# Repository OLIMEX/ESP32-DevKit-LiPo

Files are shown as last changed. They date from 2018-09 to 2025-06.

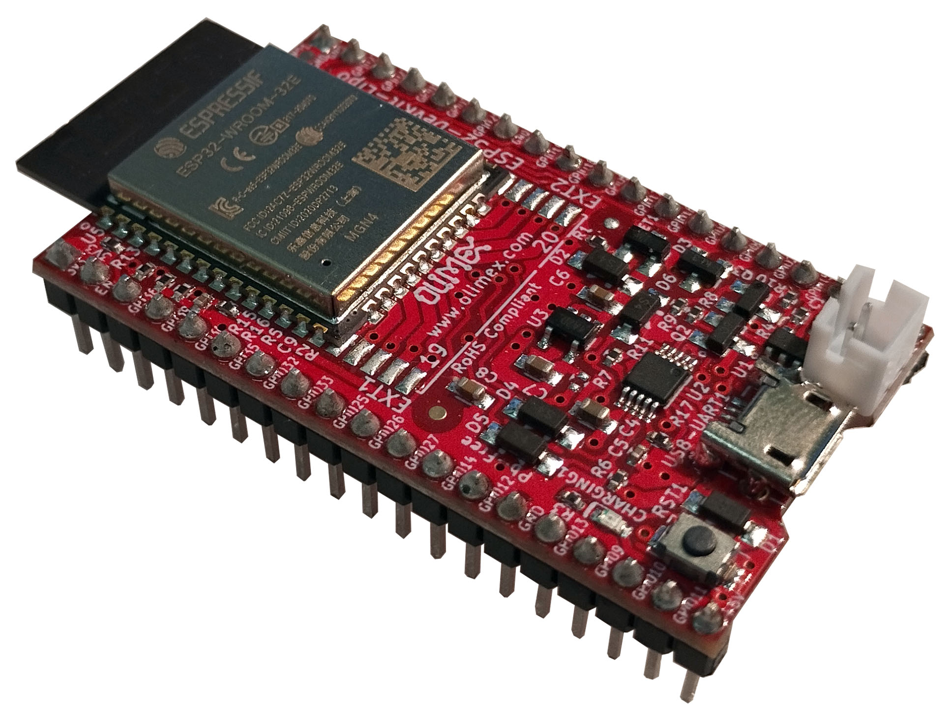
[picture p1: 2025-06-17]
DOCS/side-devkit.jpg

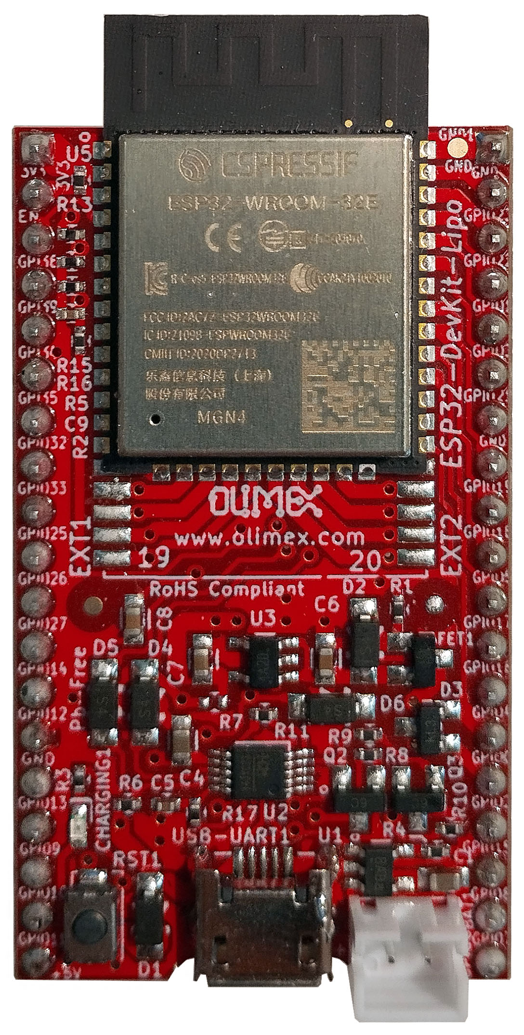
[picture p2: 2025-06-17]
DOCS/top-devkit.jpg

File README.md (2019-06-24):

# ESP32-DevKit-LiPo
Open Source Hardware OSHW ESP32 development board designed with KiCAD to be pin to pin compatible with Espressif ESP32-DevKitC, but with additional LiPo charger and battery

## License
* Hardware is released under Apache 2.0 License
* Software is released under GPL3 License
* Documentation is released under CC BY-SA 3.0

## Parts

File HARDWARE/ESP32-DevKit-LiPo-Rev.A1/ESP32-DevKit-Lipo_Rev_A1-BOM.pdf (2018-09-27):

# ESP32-DevKit-Lipo_Rev_A1-BOM 14.09.2018

Quantity | Designation | Package | Designator
3 | 220R/R0603 | R0603 | R6,R7,R10
3 | 1k/R0603 | R0603 | R8,R9,R13
1 | 1.1k/1%/R0603 | R0603 | R12
3 | 2.2k/R0603 | R0603 | R2,R3,R4
1 | 4.99k/1%/R0603 | R0603 | R11
1 | 10k/R0603 | R0603 | R1
1 | 2.2uH/1.5A/DCR<0.1R/CD32 | CD32 | L1
2 | 27pF/50V/5%/C0G/C0603 | C0603 | C2,C3
1 | 100nF/50V/20%/Y5V/C0603 | C0603 | C5
1 | 22uF/6.3V/20%/X5R/C0603 | C0603 | C4
3 | 47uF/6.3V/20%/X5R/C0805 | C0805 | C1,C6,C7
1 | BAT54C(SOT23-3) | SOT23-3 | U4
2 | 1N5822/SS34/SMA | SMA-KA | D1,D2
1 | LED/YELLOW/0603 | LED_0603 | CHARGING1
1 | LED/RED/0603 | LED_0603 | PWRLED1
2 | BC817-40(SOT23) | SOT23 | Q2,Q3
1 | WPM2015-3/TR | SOT23 | FET1
1 | BL4054B-42TPRN(SOT23-5) | SOT-23-5 | U1
1 | CH340T(SSOP20W) | SSOP-20W | U2
1 | SY8089AAAC(SOT23-5) | SOT-23-5 | U3
1 | ESP-WROOM-32 | MODULE | U5
1 | MISB-SWMM-5B-LF(USB_MICRO) | MISB-SWMM-5B_LF | USB-UART1
1 | Q12MHz/20pF/10ppm/4P/3.2x2.5mm | 3.2x2.5mm | Q1
1 | DW02S | DW02R | BAT1
2 | HN1x19 | HN1x19 | EXT1,EXT2
1 | IT-1185AU2-160G-G-TR | IT1185AU2 | RST1
2 | NA/R0603 | R0603 | R5,R14

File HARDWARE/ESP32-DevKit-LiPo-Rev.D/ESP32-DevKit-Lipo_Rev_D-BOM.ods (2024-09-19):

Qty | Designation | Package | Designator
1 | 220R/R0402 | R_0402_5MIL_DWS | R10
4 | 2.2k/R0402 | R_0402_5MIL_DWS | R9,R3,R4,R8
1 | 4.7k/R0402 | R_0402_5MIL_DWS | R11
4 | 10k/R0402 | R_0402_5MIL_DWS | R1,R6,R13,R17
1 | 220k/R0402 | R_0402_5MIL_DWS | R15
3 | 470k/R0402 | R_0402_5MIL_DWS | R2,R5,R16
2 | 100nF/10V/10%/X7R/C0402 | C_0402_5MIL_DWS | C5,C9
1 | 1uF/10V/10%/X5R/C0603 | C_0603_5MIL_DWS | C8
2 | 4.7uF/6.3V/C0603 | C_0603_5MIL_DWS | C6,C7
2 | 22uF/6.3V/20%/X5R/C0603 | C_0603_5MIL_DWS | C1,C4
5 | 1N5819S4/SOD123 | SOD-123_1C-2A_KA | D5,D4,D1,D2,D6
1 | BAT54C(SOT23-3) | SOT23-3 | D3
1 | LED/YELLOW/0603 | LED_0603_KA | CHARGING1
2 | BC817-40(SOT23) | SOT23 | Q3,Q2
1 | WPM2015-3/TR | SOT23 | FET1
1 | CH340X(MSOP-10) | MSOP-10_Pitch-0.5mm _3.00x3.00x1.00mm | U2
1 | ESP32-WROOM-32D-4MB | ESP32-WROVER_MODULE | U5
1 | HX6211A332MR | SOT-23-5 | U3
1 | BL4054B-42TPRN(SOT23-5) | SOT-23-5 | U1
1 | MISB-SWMM-5B-LF(USB_MICRO) | USB-MICRO_MISB-SWMM-5B_LF | USB-UART1
1 | DW02S | LIPO_BAT_VERTICAL_DW02S | BAT1
2 | HN1x19 | HN1x19 | EXT1,EXT2
1 | IT-1185AU2-160G-G-TR | IT1185AU2_V2 | RST1
3 | Opened | SJ_1_SMALLER | BAT_PWR_E1,BAT_SENS_E1, PWR_SENS_E1
1 | NA/R0402 | R_0402_5MIL_DWS | R7

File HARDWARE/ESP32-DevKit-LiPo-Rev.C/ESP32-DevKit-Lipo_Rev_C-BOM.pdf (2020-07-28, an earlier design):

16:26:48 | ESP32-DevKit-Lipo_Rev_C-BOM 03/19/2020
Quantity | Designation | Package | Designator
1 | 220R/R0402 | R0402 | R10
4 | 2.2k/R0402 | R0402 | R3,R4,R8,R9
4 | 10k/R0402 | R0402 | R1,R6,R13,R17
1 | 49.9k/1%/R0402 | R0402 | R12
2 | 220k/R0402 | R0402 | R11,R15
3 | 470k/R0402 | R0402 | R2,R5,R16
1 | 2.2uH/1.5A/DCR=72mR/20%/ 3.00x3.00x1.50mm/ CD32(NR3015T2R2M) | CD32 | L1
2 | 27pF/50V/5%/C0G/C0402 | C0402 | C2,C3
2 | 100nF/10V/10%/X7R/C0402 | C0402 | C5,C9
1 | 1uF/10V/10%/X5R/C0603 | C0603 | C8
4 | 22uF/6.3V/20%/X5R/C0603 | C0603 | C4,C1,C6,C7
1 | LED/YELLOW/0603 | LED_0603 | CHARGING1
1 | BAT54C(SOT23-3) | SOT23-3 | D3
4 | 1N5819S4/SOD123 | SOD-123 | D1,D2,D4,D5
2 | BC817-40(SOT23) | SOT23 | Q2,Q3
1 | WPM2015-3/TR | SOT23 | FET1
1 | BL4054B-42TPRN(SOT23-5) | SOT-23-5 | U1
1 | CH340T(SSOP20W) | SSOP-20W | U2
1 | SY8089AAAC(SOT23-5) | SOT-23-5 | U3
1 | Q12MHz/20pF/10ppm/4P/3.2x2.5mm | TSX-3.2x2.5mm | Q1
1 | MISB-SWMM-5B-LF(USB_MICRO) | MISB-SWMM-5B_LF | USB-UART1
1 | IT-1185AU2-160G-G-TR | IT1185AU2 | RST1
1 | DW02S | DW02S | BAT1
2 | HN1x19 | HN1x19 | EXT1,EXT2
1 | ESP32-WROOM-32D-4MB | ESP32-MODULE_Universal | U5
3 | Opened | SJ
1 | NA/R0402 | R0402 | R7 BAT_PWR_E1, BAT_SENS_E1, PWR_SENS_E1

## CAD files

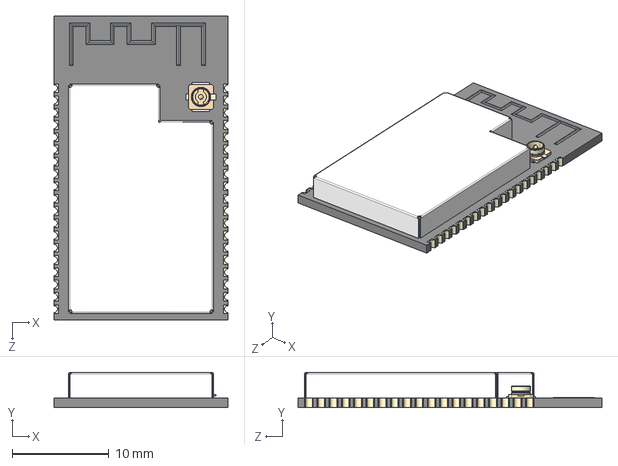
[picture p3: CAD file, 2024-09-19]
HARDWARE/ESP32-DevKit-LiPo-Rev.D/3d/ESP32-WROVER-I-56544.STEP
18.0 x 3.65 x 31.4 mm

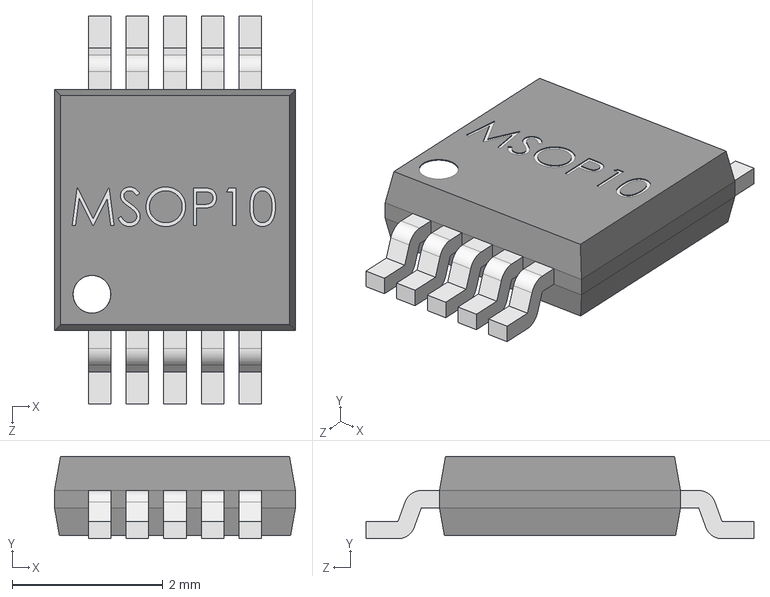
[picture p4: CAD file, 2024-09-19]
HARDWARE/ESP32-DevKit-LiPo-Rev.D/3d/MSOP10-1.step
3.20 x 1.10 x 5.15 mm

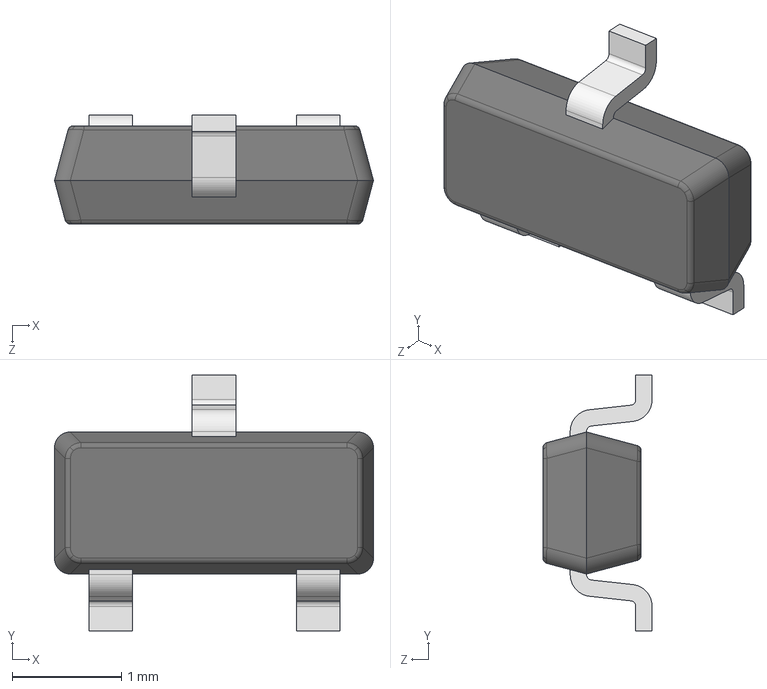
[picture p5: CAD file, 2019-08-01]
HARDWARE/ESP32-DevKit-LiPo-Rev.D/3d/BAT54.step
2.92 x 2.34 x 1.00 mm

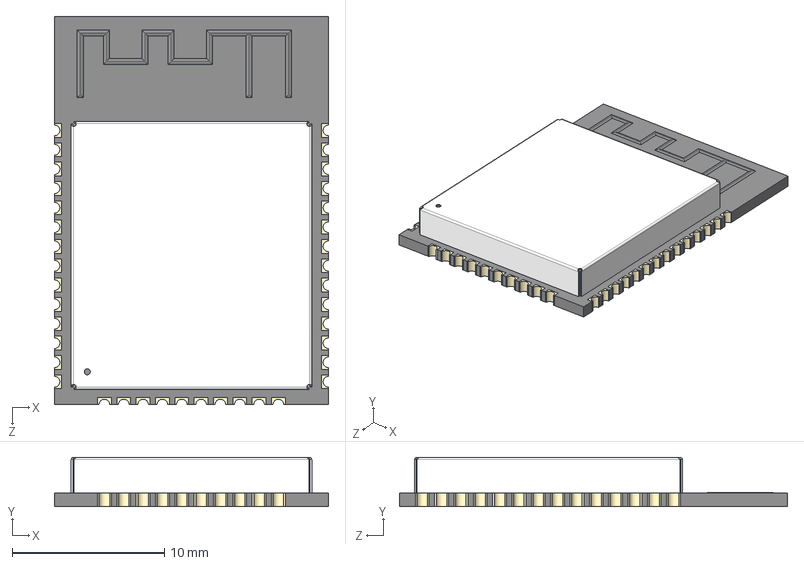
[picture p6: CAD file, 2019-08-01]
HARDWARE/ESP32-DevKit-LiPo-Rev.D/3d/ESP32-WROOM-32D-56544.STEP
18.0 x 3.25 x 25.5 mm

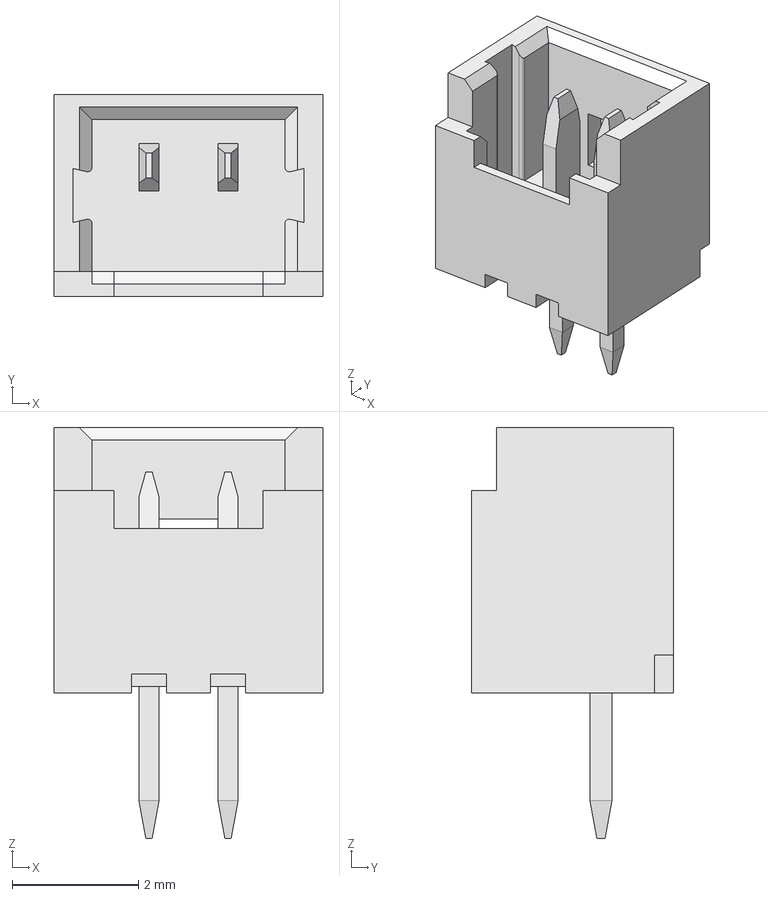
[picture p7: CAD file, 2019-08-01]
HARDWARE/ESP32-DevKit-LiPo-Rev.D/3d/Molex_PicoBlade_530470210.step
4.25 x 3.20 x 6.50 mm

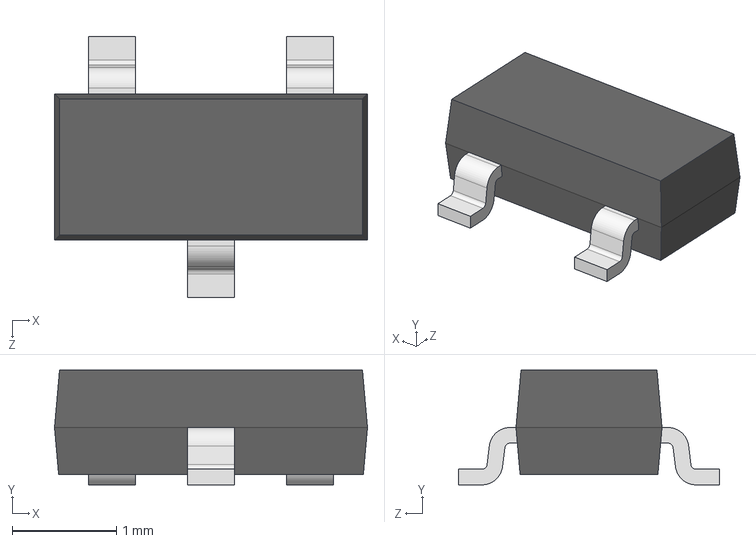
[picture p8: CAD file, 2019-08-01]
HARDWARE/ESP32-DevKit-LiPo-Rev.D/3d/SOT-23.step
3.00 x 1.10 x 2.50 mm

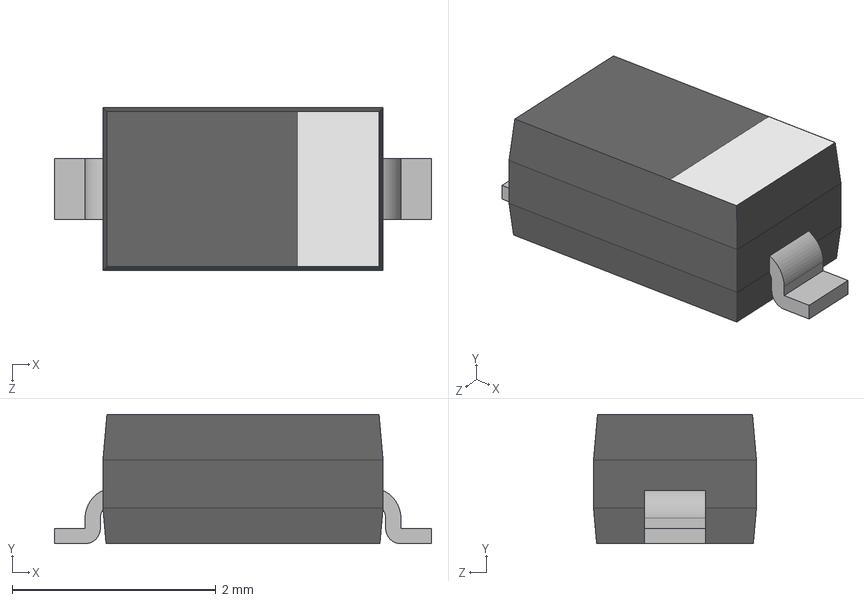
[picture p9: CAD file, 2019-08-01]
HARDWARE/ESP32-DevKit-LiPo-Rev.D/3d/SOD123.step
3.70 x 1.27 x 1.60 mm

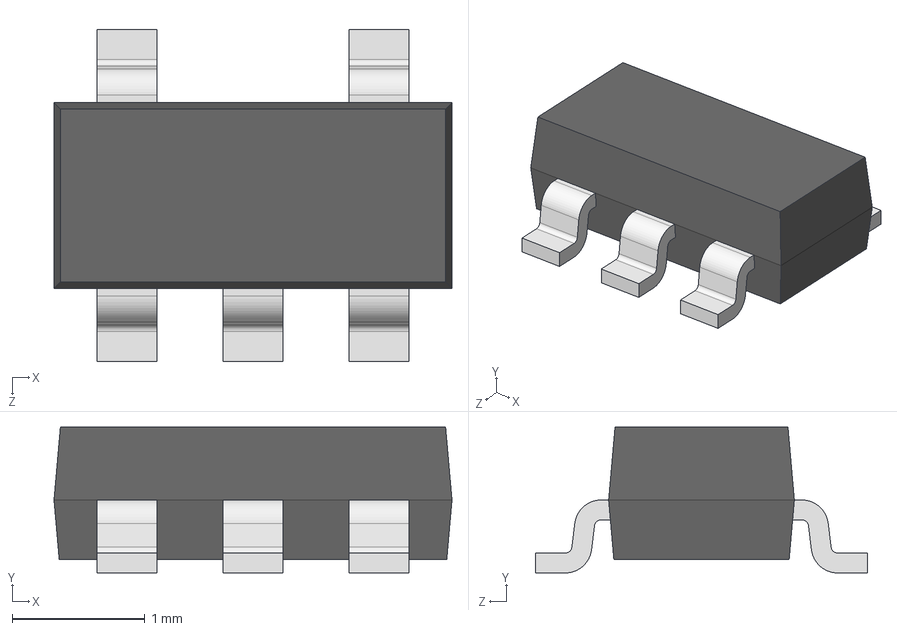
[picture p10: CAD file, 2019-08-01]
HARDWARE/ESP32-DevKit-LiPo-Rev.D/3d/SOT-23-5.step
3.00 x 1.10 x 2.50 mm

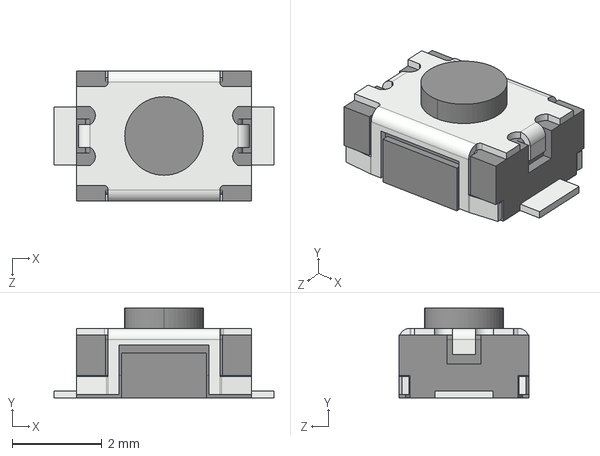
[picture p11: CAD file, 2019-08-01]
HARDWARE/ESP32-DevKit-LiPo-Rev.D/3d/it1185.step
4.90 x 2.00 x 2.90 mm

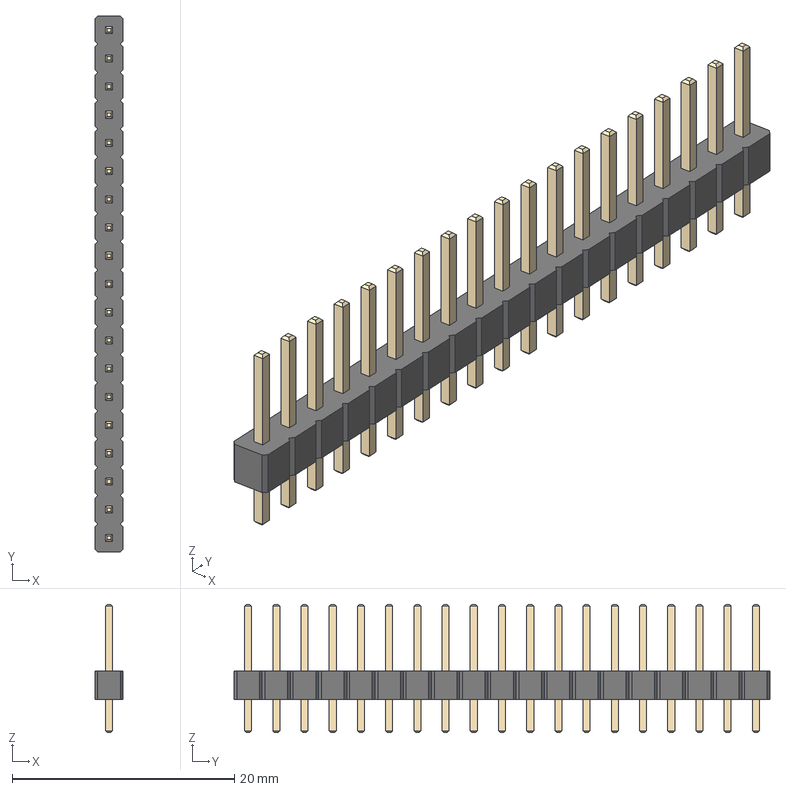
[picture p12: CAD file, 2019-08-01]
HARDWARE/ESP32-DevKit-LiPo-Rev.D/3d/HN1x19-PinHeader_1x19_P2.54mm_Vertical.step
2.54 x 48.3 x 11.5 mm

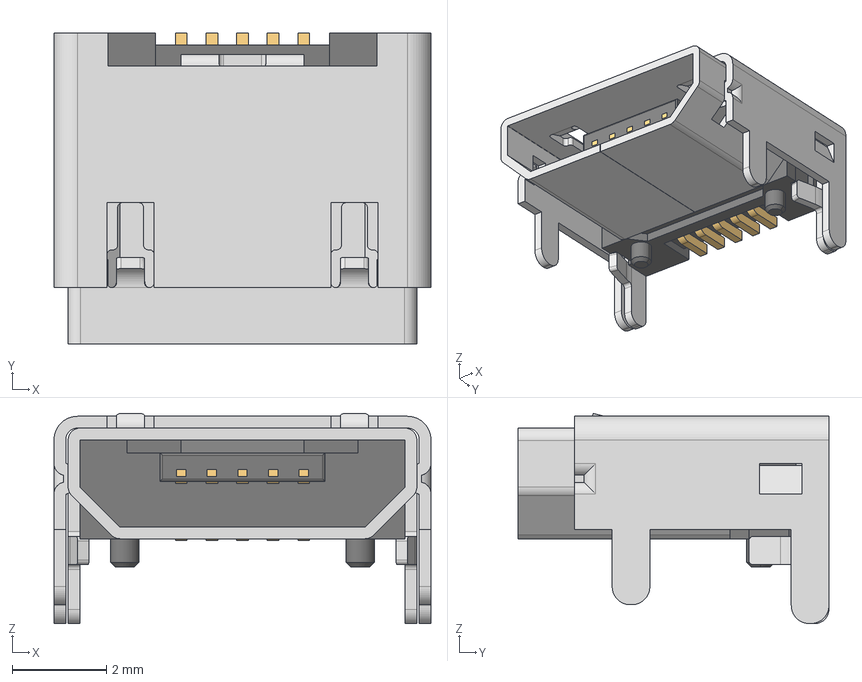
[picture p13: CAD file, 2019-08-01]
HARDWARE/ESP32-DevKit-LiPo-Rev.D/3d/usb_micro_4p.stp
8.00 x 6.60 x 4.46 mm

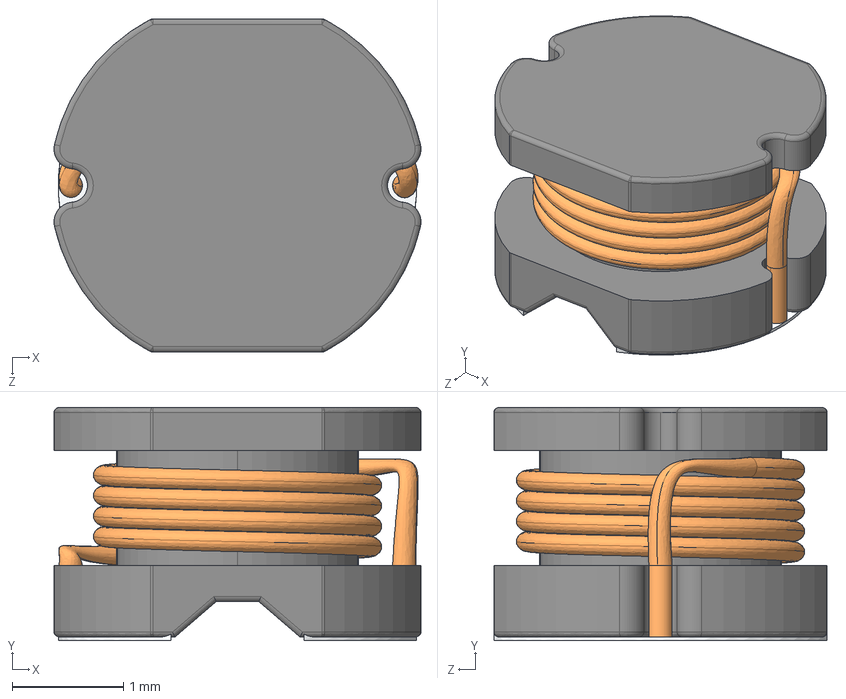
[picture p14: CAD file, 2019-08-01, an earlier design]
HARDWARE/ESP32-DevKit-LiPo-Rev.B/3d/CD32_inductor.step
3.30 x 2.10 x 3.00 mm

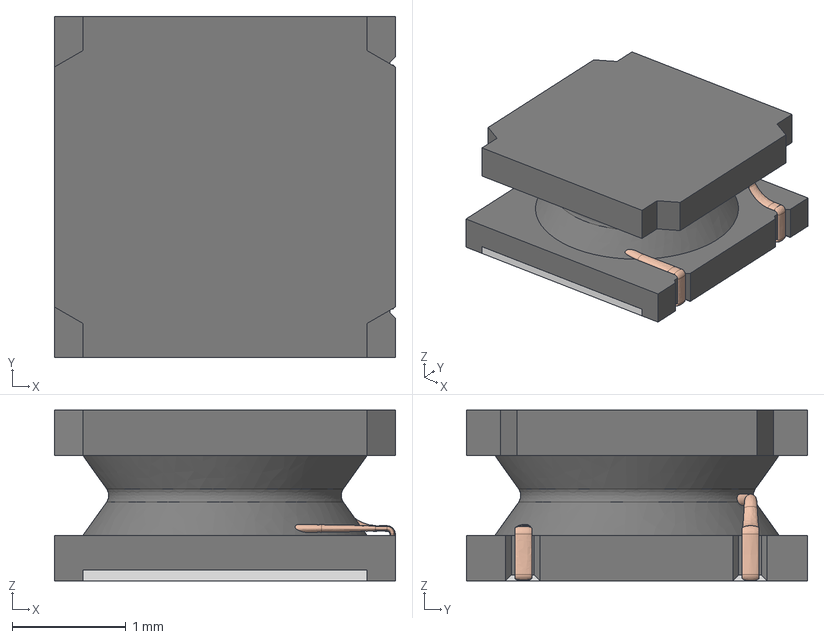
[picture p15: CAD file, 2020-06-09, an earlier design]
HARDWARE/ESP32-DevKit-LiPo-Rev.C/3d/L-CD32_shielded.step
3.00 x 3.00 x 1.50 mm

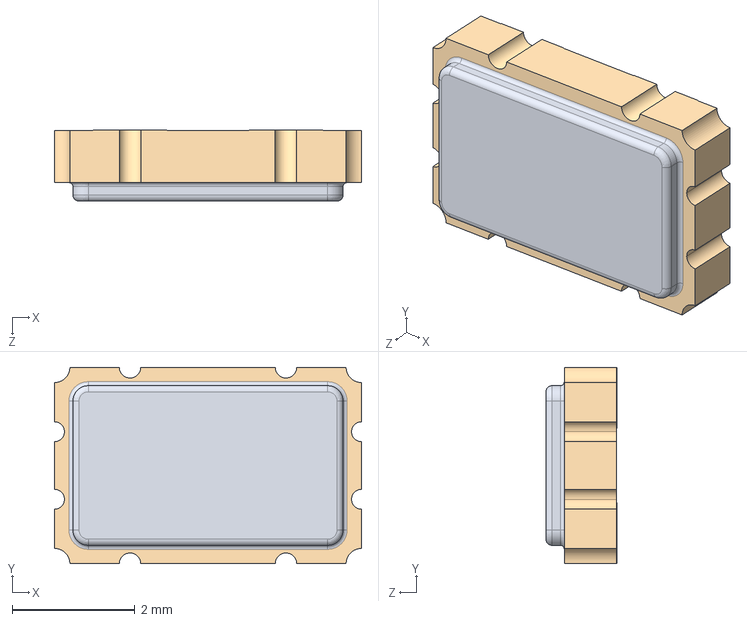
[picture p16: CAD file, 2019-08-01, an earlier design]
HARDWARE/ESP32-DevKit-LiPo-Rev.C/3d/QSG5032.step
5.00 x 3.20 x 1.16 mm

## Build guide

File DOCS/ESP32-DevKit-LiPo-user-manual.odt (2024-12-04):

=


ESP32-DevKit-LiPo

User’s Manual

Document revision 1.0, Devember 2024 | www.olimex.com

# 1. What is ESP32-DevKit-LiPo

ESP32-DevKit-LiPo is an Open Source Hardware development board that incorporates an ESP32 module. The ESP32-DevKit-LiPo board is designed and manufactured by Olimex, while the ESP32 module is designed and manufactured by Espressif systems. The design is inspired by ESP32-CoreBoard (ESP32-DevKitC) and has the same pinout, but adds Li-Po battery connector and charger. The board can operate on a Li-Po power when external power supply goes missing, allowing for handheld applications and increasing availability and reliability.

The ESP32 modules are extremely popular WIFI and BT modules due to their size, price, and very good documentation. The typical use is for WiFi and BT enabled devices. ESP32- supports low power modes including deep sleep that goes as low as 10uA.

The design has three variants, there is external antenna variant and variant with ESP32 module with extra PSRAM.

The ESP32-DevKit-LiPo board has the following features:

- ESP32-WROOM-32E (or ESP32-WROOM-32UE or ESP32-WROVER-E module, depending on variant)
- Reset button
- Micro USB connector for powering and programming
- Built-in LiPo battery charger
- LiPo battery connector
- Battery measurement and external power sense circuits
- Two columns of pins with headers soldered for easy access to all the board’s GPIOs
- Low-power design for extended operation on battery
- PCB dimensions: (1.9×1.1)" ~ (4.8×2.8)cm
- Operating temperature: -40+85C

## 1.1 ESP32-DevKit-LiPo variants

The board has 3 variants:

- ESP32-DevKit-LiPo
- ESP32-DevKit-LiPo-EA
- ESP32-WROVER-DevKit-LiPo

All board variants work in the industrial temperature range (-40+85 degrees Celsius).

ESP32-DevKit-LiPo comes with ESP32-WROOM-32E-N4 module;

ESP32-DevKit-LiPo-EA uses ESP32-WROOM-32UE-N4 module and comes with external 3dB antenna compatible with the module’s u.FL connector (ANTENNA-WIFI-U.FL (https://www.olimex.com/Products/Components/RF/ANTENNA-WIFI-BT-U.FL/));

ESP32-WROVER-DevKit-LiPo uses ESP32-WROVER-E-N4R8 module that has extra 8MB PSRAM. Notice that the WROVER module uses two extra GPIO pins for the PSRAM. Refer to the schematic and the notes on it.

## 1.2 Board use requirements

You only need a fitting USB cable and a personal computer. The board requires USB micro connector. Usually only such cable is required:

https://www.olimex.com/Products/Components/Cables/USB-CABLE-A-MICRO-1.8M/

The computer needs software compatible with ESP32 modules. Most commonly used tools are ESP-IDF and Arduino IDE with ESP32 package. You can use ESP32-DevKit-LiPo with any software tool that supports the main ESP32 module.

The board has auto-programming enabled, you don’t need to force bootloader mode. Make sure not to influence the bootstrap pins since this might influence the auto-programming feature.

## 1.3 ESP32-DevKit-LiPo Open Source Licenses

ESP32-DevKit-LiPo is Open Source Hardware, listed in OSHWA.org here:

https://certification.oshwa.org/bg000019.html

The hardware files are released under CERN OSHW (https://github.com/OLIMEX/USB-gLINK/blob/master/cern_ohl_s_v2.pdf) license.

The software is released under GPL 3 license (https://github.com/OLIMEX/USB-gLINK/blob/master/LICENSE).

The documentation is released under CC BY-SA 3.0 (https://creativecommons.org/licenses/by-sa/3.0/) license.

# 2. General board layout


On-module antenna

ESP32

module

Li-Po battery conector

Micro USB

Reset button

RST1

Battery charger LED

# 3. Power supply and consumption

ESP32-DevKit-LiPo typically consumes around 50mA of current depending on the software. The board can consume much less using the power saving modes – down to around 10uA in deep sleep mode.

The absolute maximum power ESP32-DevKit-LiPo can draw from the power supply would be the determined by the maximum input of the regulator on the power input line. Of course, consider that on-board peripherals and the main module would use some of that current. The board uses low power linear voltage regulator, it was chosen since it consumes only 1.5uA in power down mode. The downside is that it doesn’t provide a lot of current, up to a maximum of 500mA. Leave 100-150mA for the ESP32 module, you are left with 350-400mA for additional circuits.

# 4. Schematics and dimensions

ESP32-DevKit-LiPo was designed with KiCAD (free and open-source CAD tool). ESP32-DevKit-LiPo schematics and sources can be found at GitHub here:

https://github.com/OLIMEX/ESP32-DevKit-LiPo/tree/main/HARDWARE

There are also PDF exports if you don’t want to install KiCAD.

# 5. ESP32-DevKit-LiPo pinout description

All pin names and functions are printed in white print at the bottom of the board. The board’s pinout can also be seen in the schematic’s bottom left corner.

The ESP32 chip has very good multiplexer so you can set the free GPIO pins for alternative functions via software means.

The board has battery power sense and battery power measurement optional feature, that can be enabled by modifying the state of jumpers BAT_PWR_E1, PWR_SENS_E1, and BAT_SENS_E1. Close them (solder the pads together) to enable both functions, on pins GPI35 and GPI39.

# 6. Software installation

Espressif guide for Arduino IDE installation (https://docs.espressif.com/projects/arduino-esp32/en/latest/installing.html) – after installation – there is own entry for the board, it should be listed as OLIMEX ESP32-DevKit-LiPo in the board selection.

Olimex provides an Arduino example for deep sleep testing here:

https://www.olimex.com/Products/IoT/ESP32/ESP32-DevKit-LiPo/resources/timerweake-up-sketch.zip

Espressif ESP-IDF installation (https://github.com/espressif/esp-idf).

Espressif guide for PlatformIO installation (https://docs.espressif.com/projects/arduino-esp32/en/latest/installing.html).

# 7. Step-by-step Arduino IDE installation

The instructions were made under Windows 10 but should be pretty similar for different operating systems.

## 7.1. Download and install Arduino IDE

If you still don’t have Arduino IDE, navigate to the following web-address to download it:

https://www.arduino.cc/en/software/

Download the version suitable for your operating system and install it (or extract it if you use the stand-alone version). After the installation is complete, launch the Arduino IDE application.

## 7.2. Install the ESP32 support for Arduino IDE

7.2.1. Install Espressif Arduino-ESP32 stable release. To do so follow the detailed instructions here:

https://docs.espressif.com/projects/arduino-esp32/en/latest/installing.html

Short summary of what needs to be done:

- In Arduino IDE navigate to “File” → “Preferences” and in the filed that says “Additional Boards Manager URLs” append the following json link (copy-paste):

https://espressif.github.io/arduino-esp32/package_esp32_index.json

- Navigate to “Tools” → “Boards” → “Board Manager” and search for the esp32 platform. Install the latest version (3.0.4 at the time of writing this document).

If you encounter problems during the package installation make sure to check all details on the official guide from the link on the previous page.

7.2.2. Restart Arduino IDE and select the configuration for the board. Navigate to “Tools” → “Board” →under “ESP32 Arduino” tab. Find in the list “OLIMEX ESP32-DevKit-LiPo” and select it.

You can also change the properties (ESP32-WROOM and ESP32-WROVER require slightly different settings, since ESP32-WROVER has extra 8MB PSRAM). If you have WROVER version, enable PSRAM.

## 7.3. Connect the board to the computer

First connect the ESP32-DevKit-LiPo board to your computer via the micro USB connector using USB cable. In the “Windows Device Manager” you should be seeing a new CH340 device. It should be listed under “Ports” and listed as “USB-SERIAL CH340”.

## 7.4. Upload a sketch

7.4.1. After you enter the bootloader mode as mentioned above, navigate to “Tools” → “Port…” select the COM of your device (make sure to identify it from “Windows Device Manager”):

7.4.2. Compile and upload your sketch.

# 8. Document revision history

Revision 1.0 December 2024

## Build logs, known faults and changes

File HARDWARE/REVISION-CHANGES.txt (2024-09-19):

Hardware revsion A1
=========
Initial release

Major changes in hardware revision B
========
1. R5(NA/R0603) deleted to free up space on the board;
2. BAT1 connector's package changed from DW02R to DW02S;
3. Added: R2, R5, C9, BAT_PWR_E1 and BAT_SENS_E1 to allow for battery measurement;
4. U5's symbol and package changed from ESP-WROOM-32 to the ESP32-WROVER(_PCB,_IPEX,-xB)_and_ESP-WROOM-32-Universal. This allows to place either Wroom or Wrover ESP32 module;
5. L1's value changed from 2.2uH/1.5A/DCR<0.1R/CD32 to 2.2uH/1.5A/DCR=72mR/20%/3.00x3.00x1.50mm/CD32(NR3015T2R2M);
6. The PWRLED1(LED/RED/0603) and R2(2.2k/R0603) deleted to save place on the board. The CHARGING1 LED will be used for charging and power good indicator!;
8. Added: R15, R16, and PWR_SENS_E1 to allow external power ON/OFF detection;
9. U2(CH340) corrected power supply - from 3.3V to only +5V_USB. For 3.3/5V(Tx/Rx) volatage translators were used: D4 and  D4(1N5819S4/SOD123), R6 and R7. R6 and R7 were changed from 220R/R0603 to 10k/0603. Thus, CH340 will not be powered when attached to a battery - avoiding additional battery discharge!;
10. U4(BAT54C(SOT23-3)) renamed to D3;
11. R1(10k/0603) changed to 10k/0402;
12. D1 and D2 changed from 1N5822/SS34/SMA to 1N5819S4/SOD123;
13. R11 changed from 4.99k/1%/R0603 to 220k/R0402, and R12 was changed from 1.1k/1%/R0603 to 49.9k/1%/R0402 to save power consumption when on battery;
14. R14(NA/R0603) deleted to free place on the PCB;
15. R13 changed from 1k/R0603 to 10k/R0402;
16. R8 and R9 changed from 1k/R0603 to 2.2k/0402;
17. All 0805 capacitors exchanged with 0603, all 0603 resistors with 0402 and several 0603 caps changed to 0402. The BOM is completely different!
18. R2 and R5 changed from 100k/R0402 to 470k/R0402 to decrease the battery discharging;
19. R13 changed from 10k/R0402 to 470k/R0402 to decrease the battery discharging;
20. R15 changed from 49.9k/1%/R0402 to 220k/R0402 and R16 changed from 100k/R0402 to 470k/R0402;
21. The 3D models were assignend in the PCB.

Major changes in hardware revision C
========
1. Text labels: ESP-WROOM-32 and ESP32-WROVER moved from F.Silk layer to the Dwgs.User to avoid confusion;
2. Added C8(1uF/10V/10%/X5R/C0603) and changed R13 470k/R0402 to 10k/R0402 - this improves start up behavior;

Major changes in hardware revision D
========
1. STEP-down DCDC changed to HX6211A332MR, this reduces consumption in power saving modes significantly (from around 65uA down to around 10uA).
2. CH340 changed to CH340X.
3. Added diaode D6 to ESP_E (reset).
4. Added CE sign.

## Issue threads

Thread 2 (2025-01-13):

Where can I find the schematic and CAD files for the ESP32-WROVER-DevKit-Lipo?

Gaai, 2025-01-13:
It seems there are differences as in the GPIO map on here:
https://www.olimex.com/Products/IoT/ESP32/ESP32-DevKit-LiPo/resources/ESP32-WROVER-DevKit-Lipo-GPIOs.pdf
Says the battery pin is different (34 instead of 35)... So I'm wondering... what else? And would like to reference it for closer inspection for my usages anyway.

DanKoloff, 2025-01-13:
I think that the battery pin is mistake in the pinout pdf, not that it is different between WROVER and WROOM variants. Better double check the schematic:

https://github.com/OLIMEX/ESP32-DevKit-LiPo/blob/master/HARDWARE/ESP32-DevKit-LiPo-Rev.D/ESP32-DevKit-Lipo_Rev_D.pdf

The difference between WROVER (PSRAM) and WROOM (base variant, no PSRAM) modules are:

- WROVER modules require two of the pins for the PSRAM, as compared to WROOM modules that have no PSRAM but have two extra GPIOs;
- When using WROVER - GPIO16 and GPIO17 are not connected. This note is also printed at the ESP32 module's bottom left corner.

Gaai, 2025-01-13:
Alright. I hoped so. I did check the schematic and that's where I noticed the different pin from what I previously wrote down based on the pinout pdf. So I'll take the wroom schematic as definite than. Although I'm still very much interested in the wrover schematic and cad files because I was thinking of making a few adaptations to limit my total component count. So it would definitely make my life a little easier if I could use those as a base ;)

Gaai, 2025-01-13:
From what I understand however, in case they don't exist somewhere, I could simply replace the wroom module with the wrover module in those files and rework the connections (pin 16/17 for example) where needed?

DanKoloff, 2025-01-13:
We use the CAD and schematic published. The difference between the two variants is one gets WROOM module, the other the WROVER. There are literally no differences in the schematic. Only a single component is different in the BOM.

All hardware files are here:

https://github.com/OLIMEX/ESP32-DevKit-LiPo/tree/master/HARDWARE

When using WROVER there is no GPIO16 and GPIO17. So if you used these in the WROOM design you have to use other pins (not GPIO16 nor GPIO17). Also notice that GPIO16 and GPIO17 are not pin 16 and pin 17 (!) when it comes to ESP32 module numbering.

Gaai, 2025-01-13:
Yes of course. I should have said gpio16/17. And thanks for clearing that up about the schematic! Doable ;)

Closed 2025-01-13.

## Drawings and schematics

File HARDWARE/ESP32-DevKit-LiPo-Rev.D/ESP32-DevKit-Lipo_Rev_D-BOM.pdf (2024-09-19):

ESP32-DevKit-Lipo_Rev_D-BOM | 10/02/2023

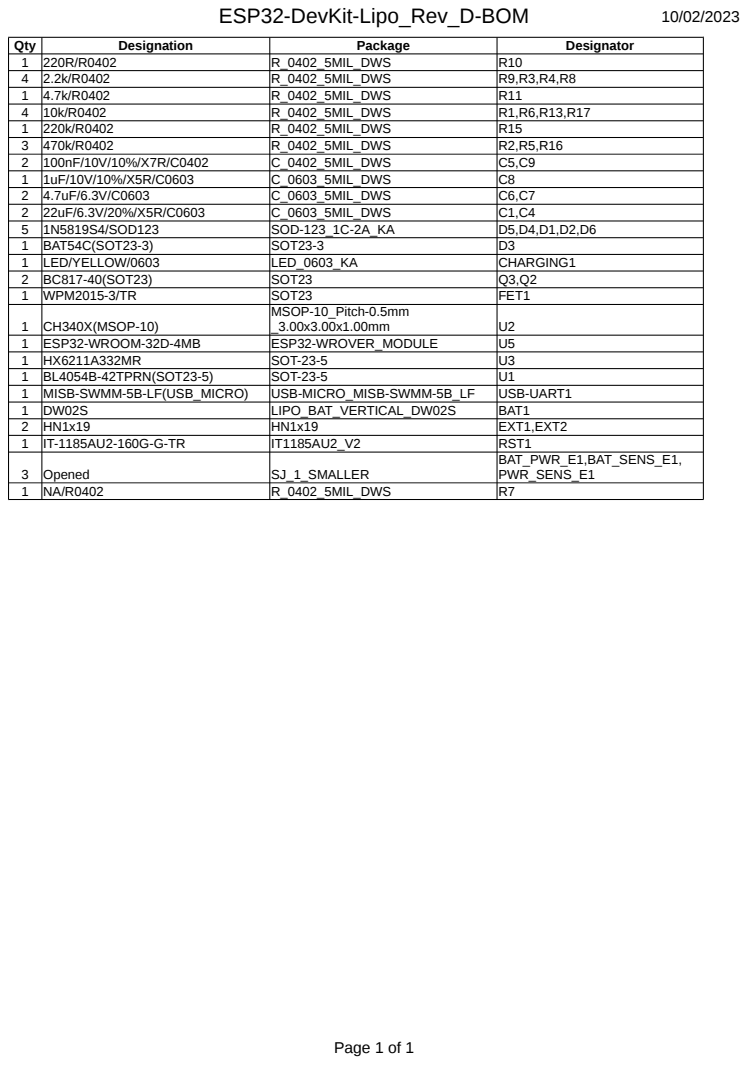
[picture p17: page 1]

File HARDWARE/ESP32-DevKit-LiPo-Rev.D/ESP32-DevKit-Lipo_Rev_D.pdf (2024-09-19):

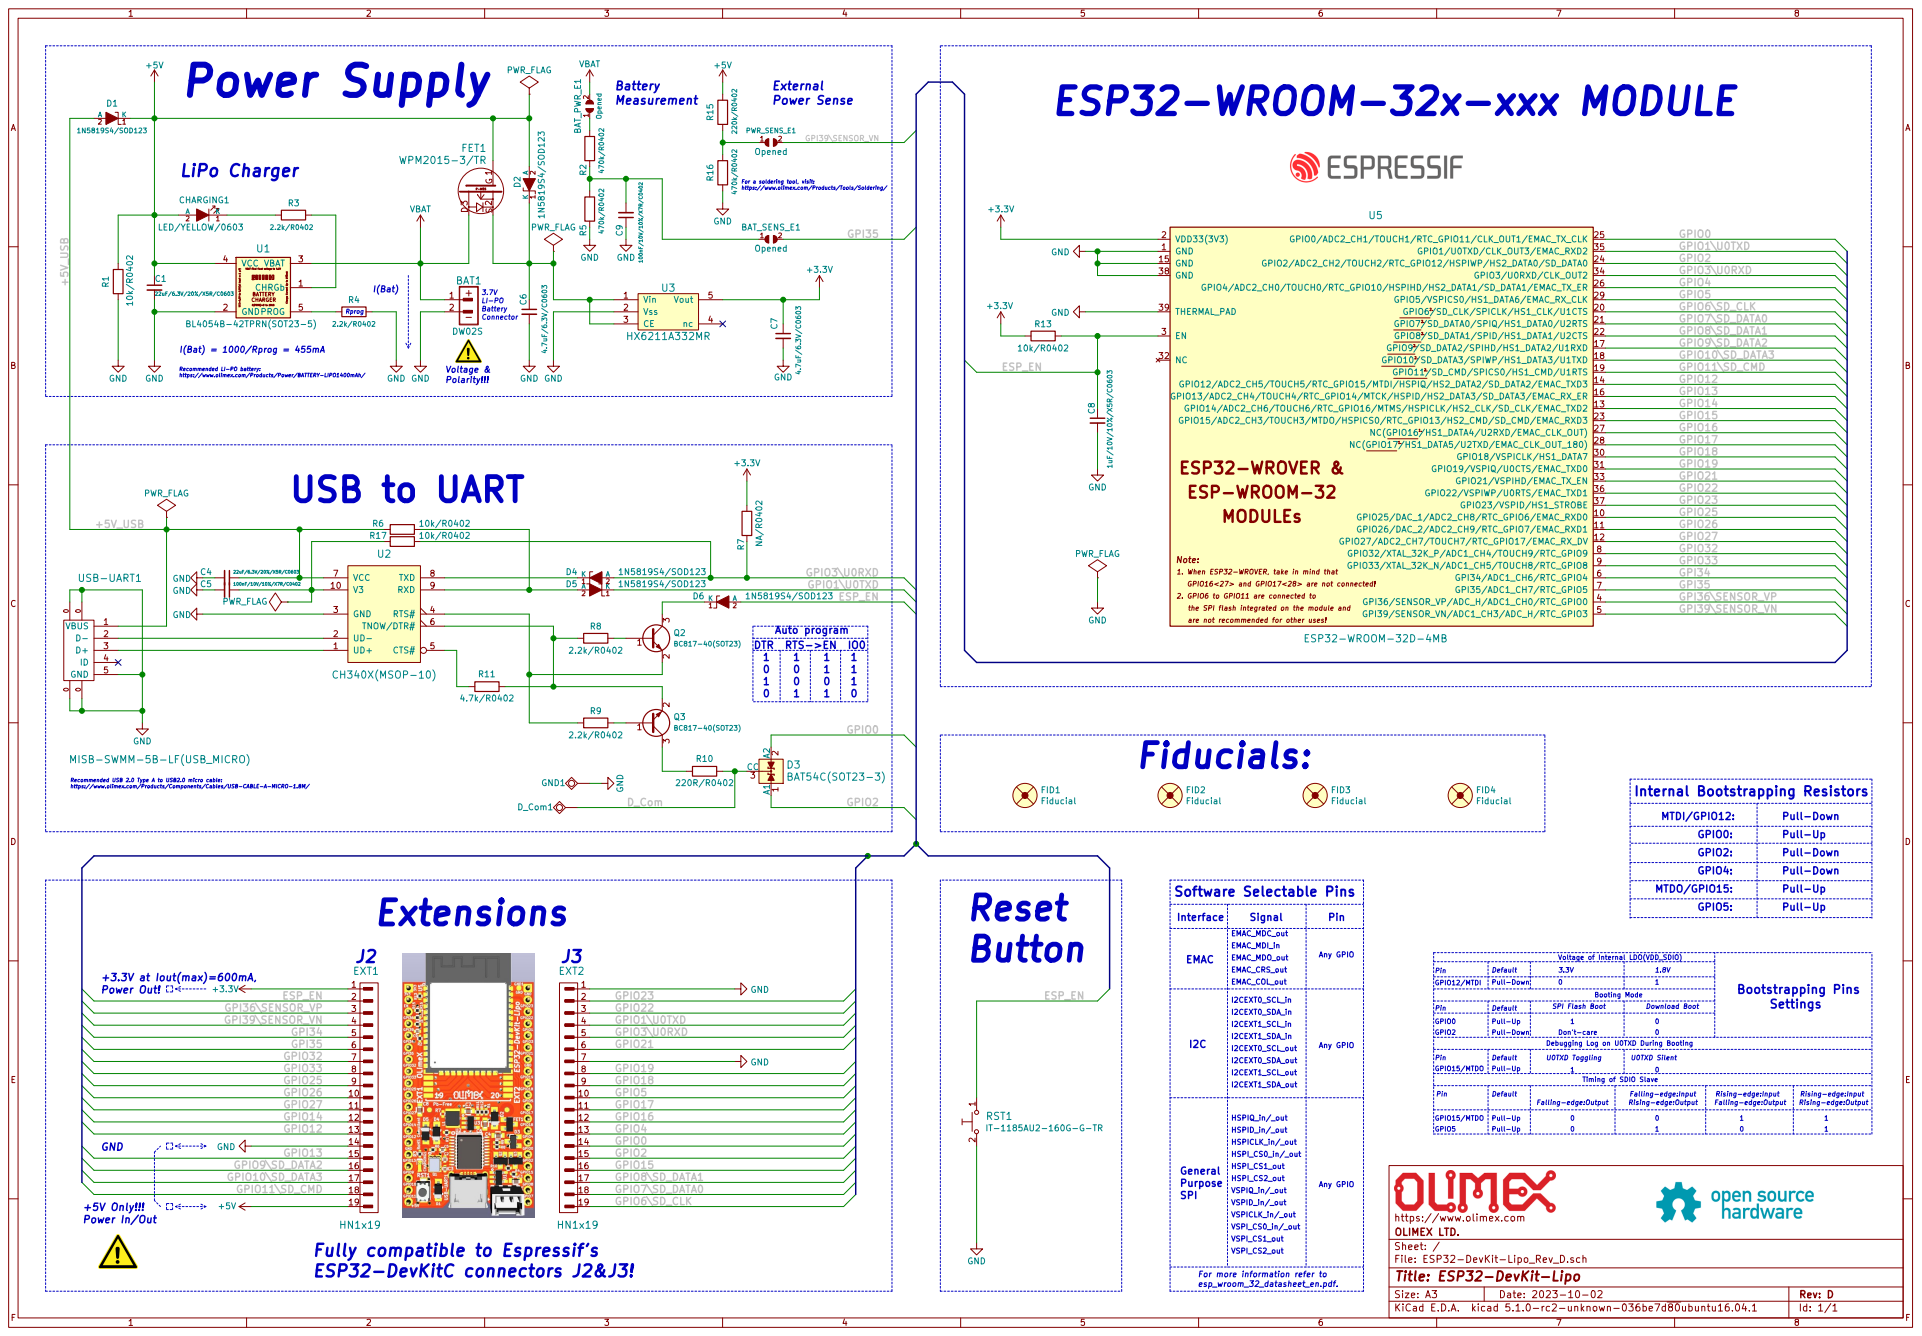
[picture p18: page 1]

2.2. 2. 2.2. 2. 2. GPIO6 to GPIO11 are connected to are not recommended for other uses! ESP-WROOM-32

1. 1. 1. When ESP32-WROVER, take in mind that
ESP32-WROVER &

GPIO16<27> and GPIO17<28> are not connected! MODULEs

MISB-SWMM-5B-LF(USB_MICRO) GND

EMAC_COL_out Interface EMAC EMAC_MDC_out EMAC_MDI_in EMAC_MDO_out EMAC_CRS_out | Any GPIO

Signal | Pin

Settings

1 Rising-edge:Input

File: ESP32-DevKit-Lipo_Rev_D.sch Sheet: / OLIMEX LTD. https://www.olimex.com

Id: 1/1 Title: ESP32-DevKit-Lipo

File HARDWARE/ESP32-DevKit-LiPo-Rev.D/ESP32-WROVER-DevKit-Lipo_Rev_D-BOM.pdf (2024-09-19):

ESP32-WROVER-DevKit-Lipo_Rev_D-BOM | 10/02/2023

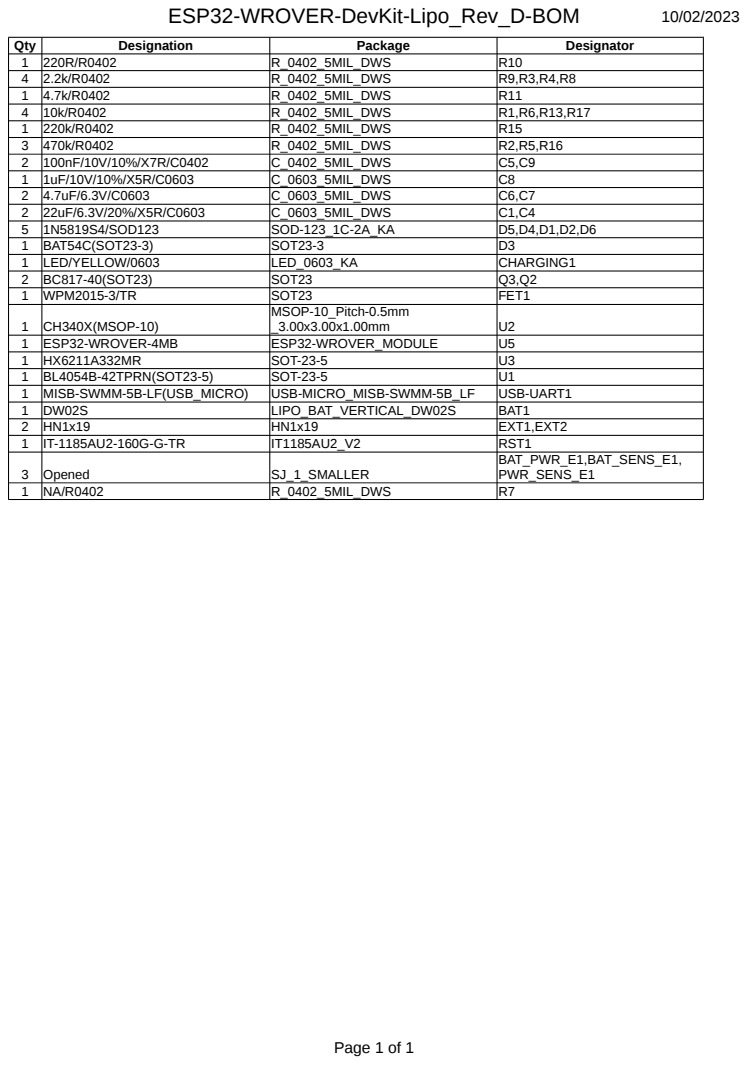
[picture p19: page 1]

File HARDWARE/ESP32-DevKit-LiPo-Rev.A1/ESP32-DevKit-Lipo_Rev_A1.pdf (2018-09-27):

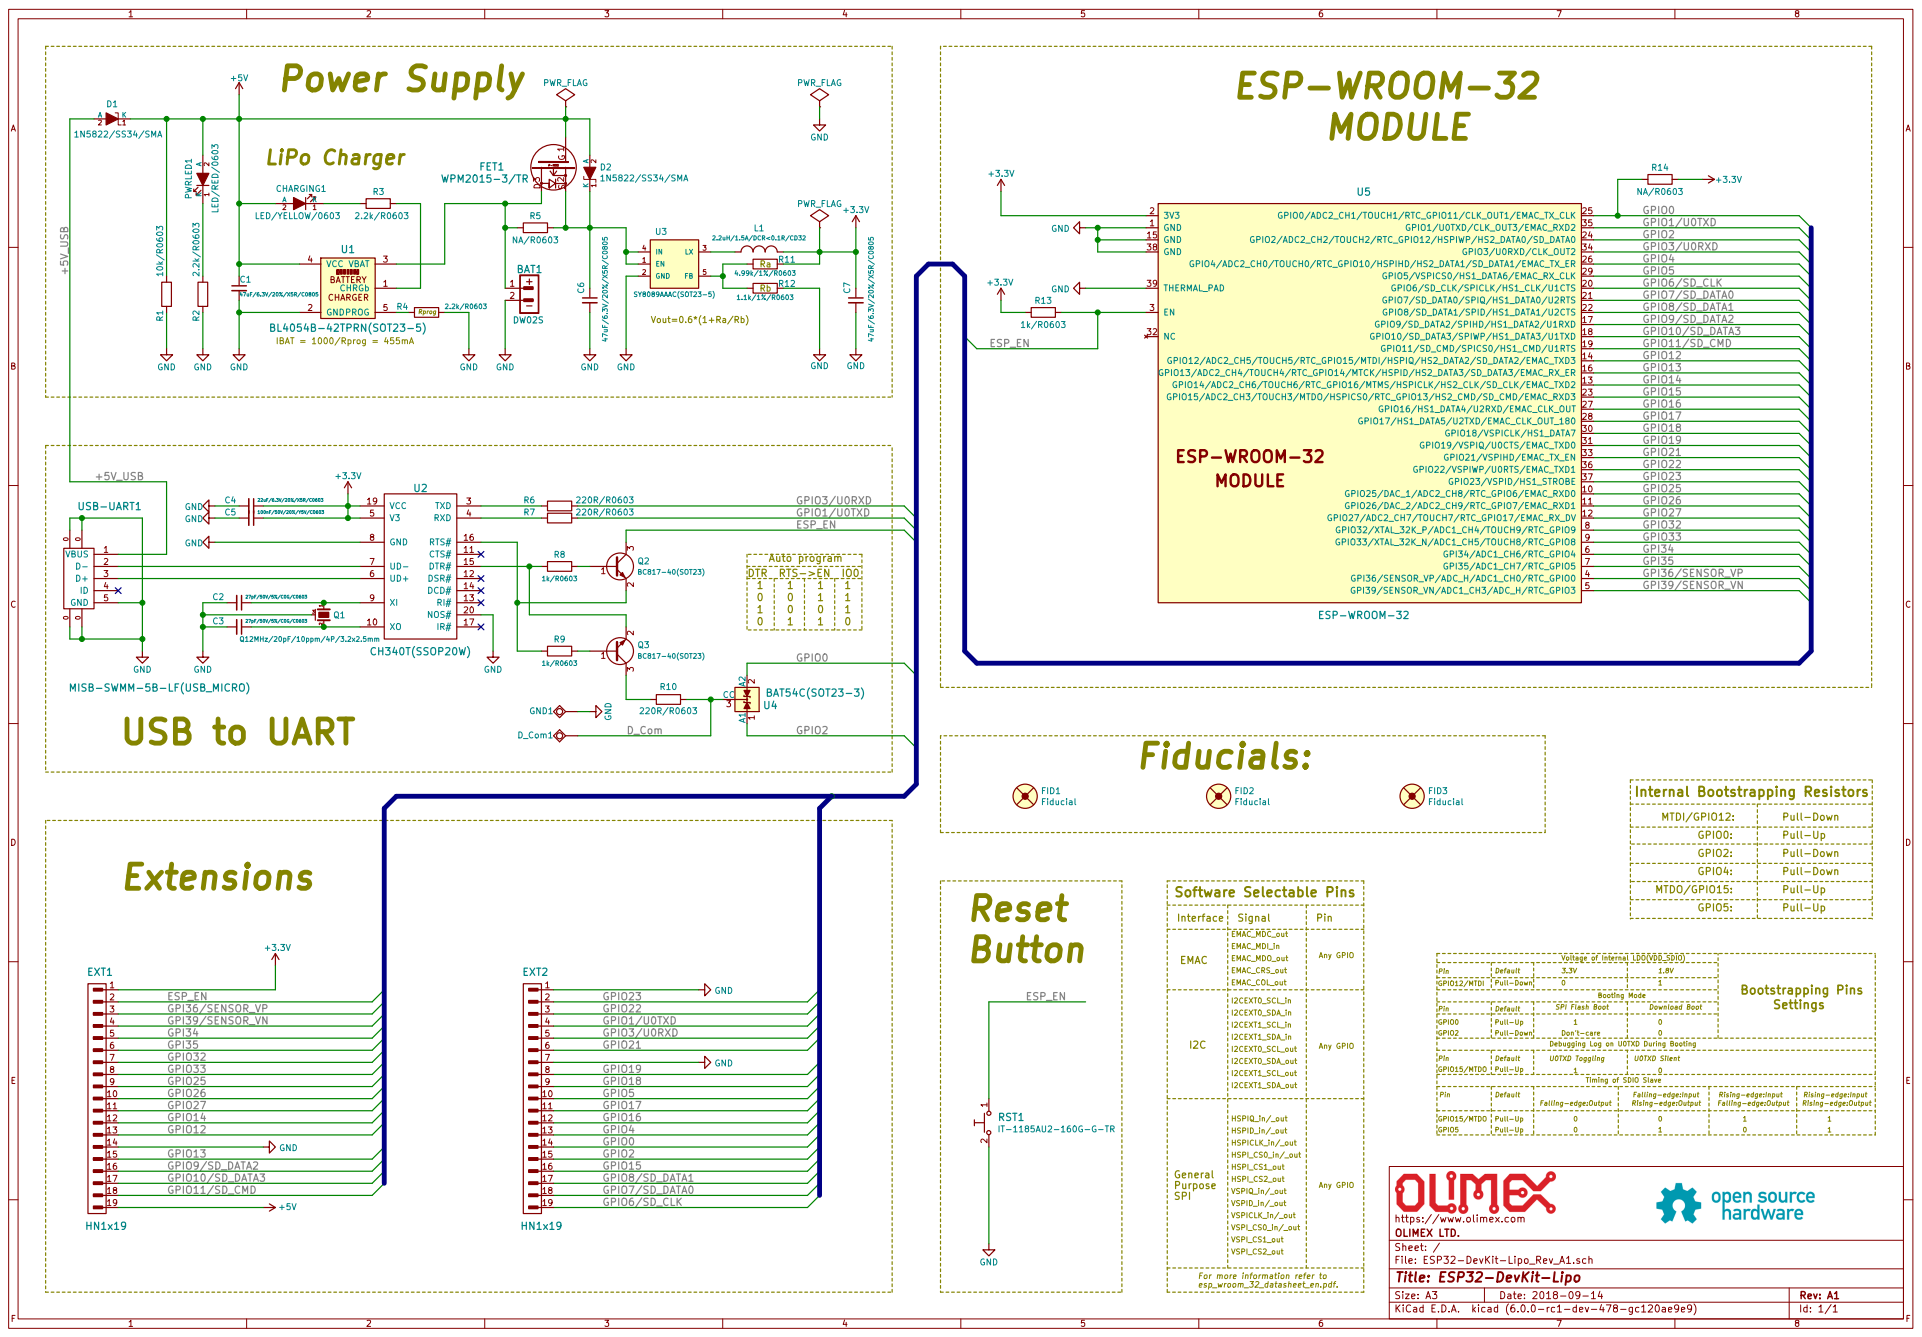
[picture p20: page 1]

2 PWRLED1 LED/RED/0603 GND GND GND

Reset Button GND | ESP_EN | File: ESP32-DevKit-Lipo_Rev_A1.sch Sheet: / OLIMEX LTD. https://www.olimex.com GNDGND1

Internal Bootstrapping Resistors MTDI/GPIO12: | Pull-Down GPIO0: Pull-Up GPIO2: Pull-Down GPIO4: Pull-Down MTDO/GPIO15: Pull-Up GPIO5: Pull-Up

EMAC_COL_out Interface EMAC EMAC_MDC_out EMAC_MDI_in EMAC_MDO_out EMAC_CRS_out | Any GPIO

Signal | Pin

Id: 1/1 Title: ESP32-DevKit-Lipo

Rev: A1 | F Date: 2018-09-14 KiCad E.D.A. kicad (6.0.0-rc1-dev-478-gc120ae9e9) Size: A3

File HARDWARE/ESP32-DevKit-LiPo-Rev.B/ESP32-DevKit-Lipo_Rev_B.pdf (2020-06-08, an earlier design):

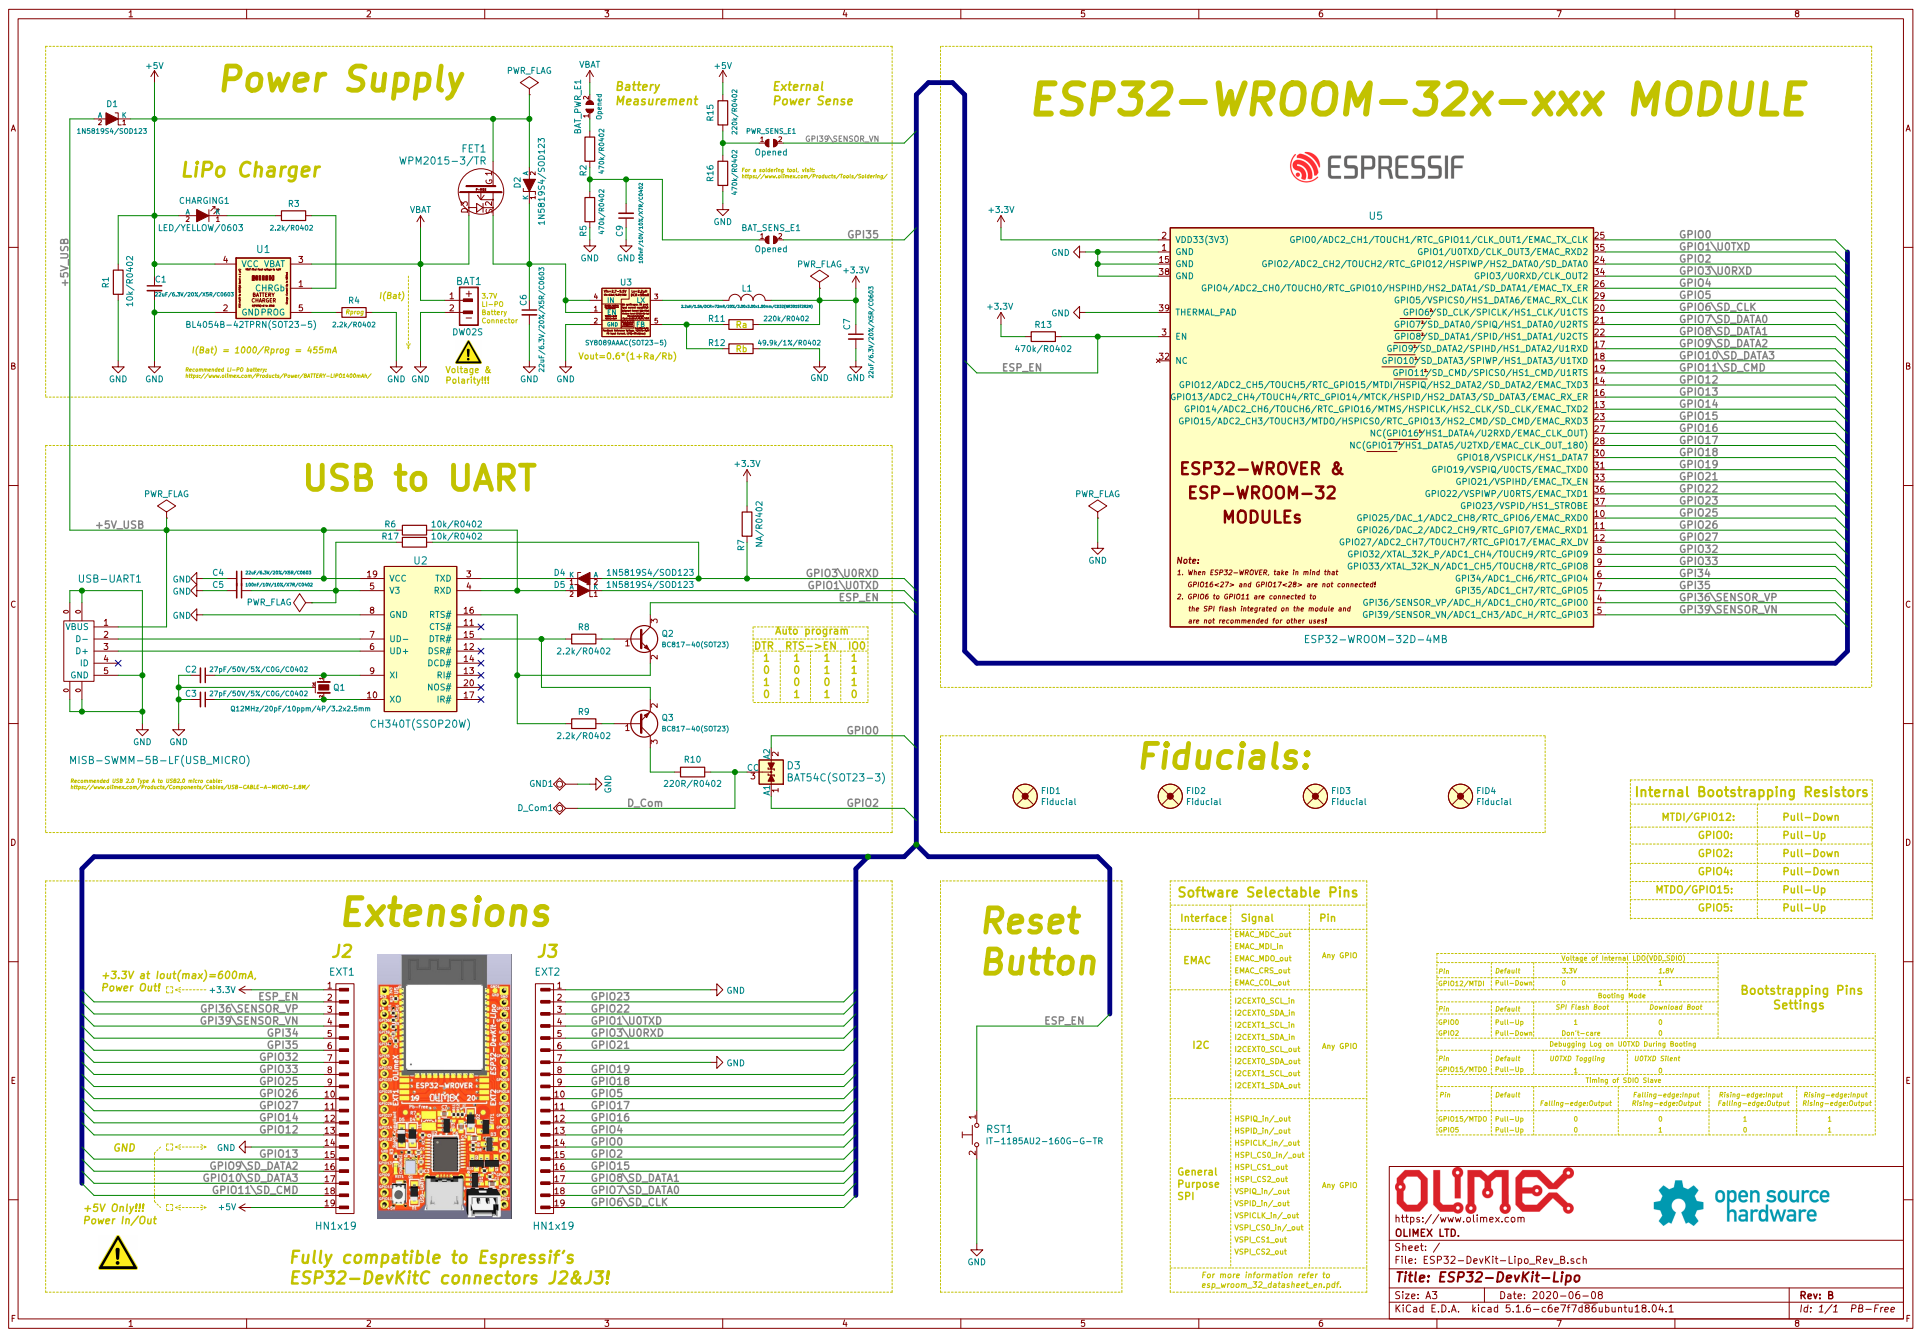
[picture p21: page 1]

load current capability! Lx=2.2H

Do not float. Enable control. FB Input Current, I(FB)=50nA(max) Feedback Reference Voltage, V(REF)=0.6V

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

Recommended LI-PO battery: https://www.olimex.com/Products/Power/BATTERY-LIPO1400mAh/

1. 1. 1. When ESP32-WROVER, take in mind that
ESP32-WROVER &

GPIO16<27> and GPIO17<28> are not connected! MODULEs

Recommended USB 2.0 Type A to USB2.0 micro cable: https://www.olimex.com/Products/Components/Cables/USB-CABLE-A-MICRO-1.8M/

EMAC | Pull-Down Reset

Interface

Debugging Log on U0TXD During Booting

File: ESP32-DevKit-Lipo_Rev_B.sch Sheet: / OLIMEX LTD. https://www.olimex.com

Fully compatible to Espressif's
ESP32-DevKitC connectors J2&J3!

Id: 1/1 PB-Free Title: ESP32-DevKit-Lipo

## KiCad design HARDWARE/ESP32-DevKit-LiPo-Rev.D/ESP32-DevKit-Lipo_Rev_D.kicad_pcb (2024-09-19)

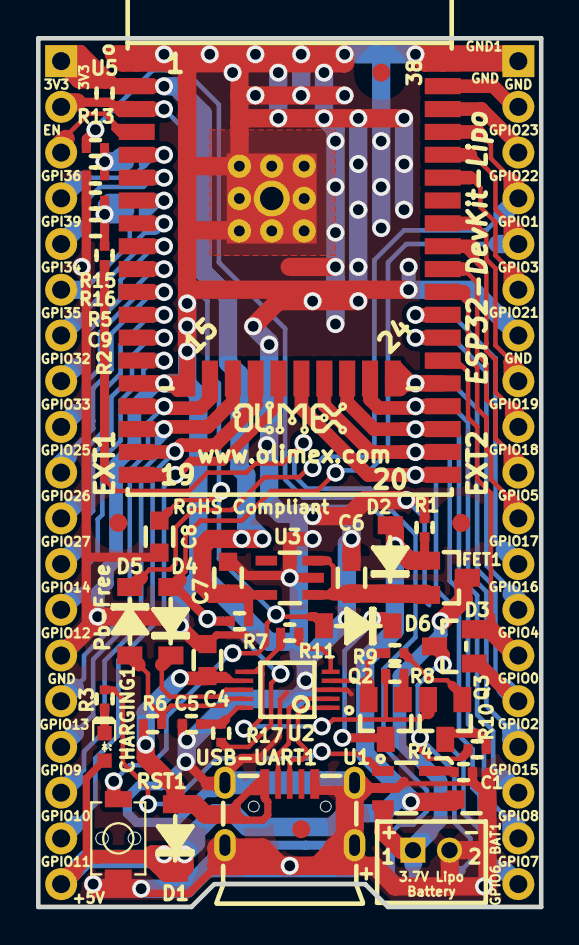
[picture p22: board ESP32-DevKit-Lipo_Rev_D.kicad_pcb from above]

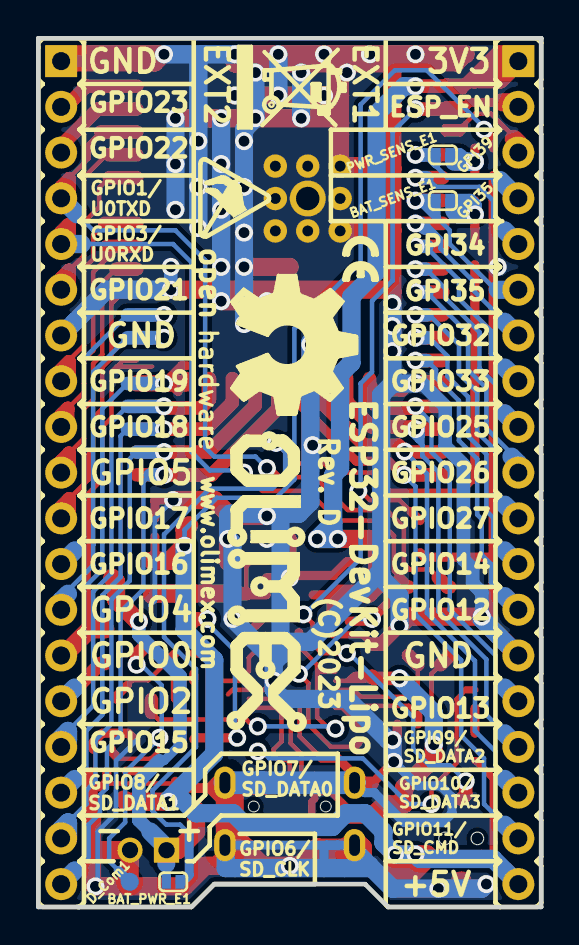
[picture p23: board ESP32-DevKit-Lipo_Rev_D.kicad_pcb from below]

Board: 2 copper layers, 27.9 x 48.3 mm, 56 parts (11 on the bottom side), 58 nets.

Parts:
BAT1: DW02S; LIPO_BAT_VERTICAL_DW02S
BAT_PWR_E1: Opened; SJ_1_SMALLER
BAT_SENS_E1: Opened; SJ_1_SMALLER
C1, C4: 22uF/6.3V/20%/X5R/C0603; C_0603_5MIL_DWS
C5, C9: 100nF/10V/10%/X7R/C0402; C_0402_5MIL_DWS
C6, C7: 4.7uF/6.3V/C0603; C_0603_5MIL_DWS
C8: 1uF/10V/10%/X5R/C0603; C_0603_5MIL_DWS
CHARGING1: LED/YELLOW/0603; LED_0603_KA
D1, D2, D4, D5, D6: 1N5819S4/SOD123; SOD-123_1C-2A_KA
D3: BAT54C(SOT23-3); SOT23-3
D_Com1: TESTPAD; TESTPAD_40-ROUND
EXT1, EXT2: HN1x19
FET1: WPM2015-3/TR; SOT23
FID1: Fiducial; Fiducial1x3_Past
FID2, FID3, FID4: Fiducial; Fiducial1x3
GND1: TESTPAD; TESTPAD_40-ROUND
Logo_OSHW: LOGO_OPENHARDWARE_8x8
Olimex_Logo_Big: OLIMEX_LOGO_TB
Olimex_Logo_Small: LOGO_OLIMEX_80
PWR_SENS_E1: Opened; SJ_1_SMALLER
Q2, Q3: BC817-40(SOT23); SOT23
R1, R6, R13, R17: 10k/R0402; R_0402_5MIL_DWS
R2, R5, R16: 470k/R0402; R_0402_5MIL_DWS
R3, R4, R8, R9: 2.2k/R0402; R_0402_5MIL_DWS
R7: NA/R0402; R_0402_5MIL_DWS
R10: 220R/R0402; R_0402_5MIL_DWS
R11: 4.7k/R0402; R_0402_5MIL_DWS
R15: 220k/R0402; R_0402_5MIL_DWS
RST1: IT-1185AU2-160G-G-TR; IT1185AU2_V2
Sign_Antistatic: Val**; LOGO_ANTISTATIC_SMALL_4.5mmX2.8mm
Sign_CE_Small: CE_Sign_Small
Sign_RecycleBin: LOGO_RECYCLEBIN_1
U1: BL4054B-42TPRN(SOT23-5); SOT-23-5
U2: CH340X(MSOP-10); MSOP-10_Pitch-0.5mm_3.00x3.00x1.00mm
U3: HX6211A332MR; SOT-23-5
U5: ESP32-WROOM-32D-4MB; ESP32-WROVER_MODULE
USB-UART1: MISB-SWMM-5B-LF(USB_MICRO); USB-MICRO_MISB-SWMM-5B_LF

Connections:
+3.3V: C7.1, EXT1.1, R7.2, R13.1, U3.5, U5.2
+5V: C1.1, CHARGING1.2, D1.1, D2.2, EXT1.19, FET1.1, R1.1, R15.1, U1.4
/+5V_USB: C4.1, D1.2, R6.1, U2.7, USB-UART1.1
/D_Com: D3.3, D_Com1.1, R10.2
/ESP_EN: C8.1, D6.2, EXT1.2, R13.2, RST1.1, U5.3
/GPI34: EXT1.5, U5.6
/GPI35: BAT_SENS_E1.2, EXT1.6, U5.7
/GPI36\SENSOR_VP: EXT1.3, U5.4
/GPI39\SENSOR_VN: EXT1.4, PWR_SENS_E1.2, U5.5
/GPIO0: D3.2, EXT2.14, U5.25
/GPIO1\U0TXD: D5.1, EXT2.4, U5.35
/GPIO2: D3.1, EXT2.15, U5.24
/GPIO3\U0RXD: D4.2, EXT2.5, R7.1, R17.2, U5.34
/GPIO4: EXT2.13, U5.26
/GPIO5: EXT2.10, U5.29
/GPIO6\SD_CLK: EXT2.19, U5.20
/GPIO7\SD_DATA0: EXT2.18, U5.21
/GPIO8\SD_DATA1: EXT2.17, U5.22
/GPIO9\SD_DATA2: EXT1.16, U5.17
/GPIO10\SD_DATA3: EXT1.17, U5.18
/GPIO11\SD_CMD: EXT1.18, U5.19
/GPIO12: EXT1.13, U5.14
/GPIO13: EXT1.15, U5.16
/GPIO14: EXT1.12, U5.13
/GPIO15: EXT2.16, U5.23
/GPIO16: EXT2.12, U5.27
/GPIO17: EXT2.11, U5.28
/GPIO18: EXT2.9, U5.30
/GPIO19: EXT2.8, U5.31
/GPIO21: EXT2.6, U5.33
/GPIO22: EXT2.3, U5.36
/GPIO23: EXT2.2, U5.37
/GPIO25: EXT1.9, U5.10
/GPIO26: EXT1.10, U5.11
/GPIO27: EXT1.11, U5.12
/GPIO32: EXT1.7, U5.8
/GPIO33: EXT1.8, U5.9
GND: BAT1.2, C1.2, C4.2, C5.2, C6.2, C7.2, C8.2, C9.1, EXT1.14, EXT2.1, EXT2.7, GND1.1, R1.2, R4.2, R5.2, R16.2, RST1.2, U1.2, U2.3, U3.2, U5.1, U5.15, U5.38, U5.39, USB-UART1.0, USB-UART1.5
unnamed: BAT_PWR_E1.1, R2.1
unnamed: BAT_SENS_E1.1, C9.2, R2.2, R5.1
unnamed: C5.1, R17.1, U2.10
unnamed: C6.1, D2.1, FET1.2, U3.1, U3.3
unnamed: CHARGING1.1, R3.1
unnamed: D4.1, U2.8
unnamed: D5.2, R6.2, U2.9
unnamed: D6.1, Q2.3
unnamed: PWR_SENS_E1.1, R15.2, R16.1
unnamed: Q2.1, R8.2
unnamed: Q2.2, R9.1, U2.4
unnamed: Q3.1, R9.2
unnamed: Q3.2, R8.1, R11.1, U2.6
unnamed: Q3.3, R10.1
unnamed: R3.2, U1.1
unnamed: R4.1, U1.5
unnamed: R11.2, U2.5
unnamed: U2.1, USB-UART1.3
unnamed: U2.2, USB-UART1.2
VBAT: BAT1.1, BAT_PWR_E1.2, FET1.3, U1.3

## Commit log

2018-09-27 initial Rev.A1
    [ESP32-DevKit-Lipo_Rev_A-B.Cu.gbr, ESP32-DevKit-Lipo_Rev_A-B.Mask.gbr, ESP32-DevKit-Lipo_Rev_A-B.Paste.gbr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]
2020-06-08 Update
    Revision B
    [BAT54.step, CD32_inductor.step, ESP32-DevKit-Lipo_Rev_B-BOM.ods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]
2020-07-28 Update
    Hardware revision C files
    [BAT54.step, ESP32-DevKit-Lipo_Rev_C-BOM.ods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]
2024-09-19 Updated
    Added revision D files
    [BAT54.step, ESP32-DevKit-Lipo_Rev_D-BOM.ods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]

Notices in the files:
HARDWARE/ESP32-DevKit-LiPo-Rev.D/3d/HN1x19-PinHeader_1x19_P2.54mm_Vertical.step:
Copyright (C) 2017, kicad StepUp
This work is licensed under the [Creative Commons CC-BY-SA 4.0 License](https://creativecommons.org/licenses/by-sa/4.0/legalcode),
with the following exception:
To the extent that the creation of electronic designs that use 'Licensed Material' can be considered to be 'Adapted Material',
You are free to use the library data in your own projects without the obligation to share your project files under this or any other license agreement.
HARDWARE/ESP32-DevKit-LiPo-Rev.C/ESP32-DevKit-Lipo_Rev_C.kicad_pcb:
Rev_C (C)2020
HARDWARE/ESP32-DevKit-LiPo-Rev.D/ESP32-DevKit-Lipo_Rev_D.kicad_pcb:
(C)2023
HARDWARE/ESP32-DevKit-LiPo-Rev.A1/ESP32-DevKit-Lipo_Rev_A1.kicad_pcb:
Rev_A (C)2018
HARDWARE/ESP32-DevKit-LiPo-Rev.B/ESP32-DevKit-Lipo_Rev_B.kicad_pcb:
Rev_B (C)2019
